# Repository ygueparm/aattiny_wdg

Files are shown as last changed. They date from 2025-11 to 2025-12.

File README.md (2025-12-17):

# Another ATtiny85 Watchdog for ESP32

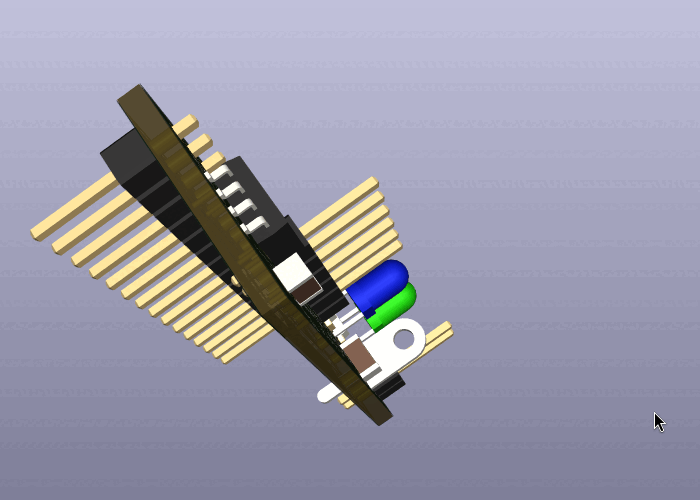
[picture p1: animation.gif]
Animation du projet


Ce projet fournit un **watchdog externe** pour ESP32, compatible avec **Arduino IDE 2.x**.

---

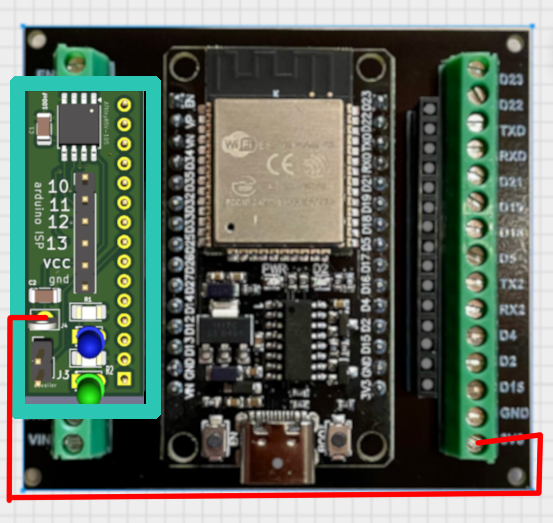
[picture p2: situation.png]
mise en situation


## 🔧 Code à inclure dans votre projet ESP32

```cpp
#define WATCHDOG_EXT         25 // IO ESP32

// Configuration du watchdog
extern bool watchdogState;
extern unsigned long previousMillisWD;
extern const long intervalWD;

void setup() {
  unsigned long previousMillisWD = 0; 
const long intervalWD = 200;  //clignotement 500 >1.6hz
bool watchdogState = true;
}

void loop() {
  // Watchdog externe créant un clignotement < 1.6 Hz
  unsigned long currentMillisWD = millis();

  if (currentMillisWD - previousMillisWD >= intervalWD) {
    previousMillisWD = currentMillisWD;
    watchdogState = !watchdogState;  // Inverse l'état
    digitalWrite(WATCHDOG_EXT, watchdogState);
  }

  // ... reste de votre code
}
```

---

# 🔌 Programmation ISP de l'ATtiny85

Pour programmer l'ATtiny85, vous devez utiliser **Arduino comme ISP**. NE SURTOUT PAS CONNECTEZ la carte a lesp32 pendant la programmation

brochage pour utiliser larduino uno comme programateur : 

'''
| Arduino Uno | ATtiny85 (broche physique) | Sérigraphie | Fonction |
| --- | --- | --- | --- |
| **10** | 1 | **P5** | RESET |
| **11** | 5 | **P0** | MOSI |
| **12** | 6 | **P1** | MISO |
| **13** | 7 | **P2** | SCK |
| **5V** | 8 | **VCC** | Alim +5V |
| **GND** | 4 | **GND** | Masse |
'''

## 1. Charger ArduinoISP

Dans l'IDE Arduino :

* *File > Examples > ArduinoISP*
* Téléversez sur votre Arduino UNO/Nano (le programmateur).

## 2. Ajouter la carte ATtiny85

* *File > Preferences*
* Dans **Additional board manager URLs**, ajoutez :

```
https://raw.githubusercontent.com/damellis/attiny/ide-1.6.x-boards-manager/package_damellis_attiny_index.json
```

Ensuite :

* *Tools > Board > Boards Manager*
* Recherchez **attiny** et installez.

## 3. Configuration

Dans *Tools* :

* **Board** : ATtiny85
* **Clock** : 1 MHz (interne)
* **Programmer** : Arduino as ISP

###  Première utilisation de l'ATtiny85

1. Ne soudez que l'ATtiny85 et les pins de programmation.
2. *Tools > Burn Bootloader* (installe les fuses corrects).
3. Votre ATtiny85 est maintenant prêt pour le projet.

 * fichier .ino >   aattiny_wdg/attiny_watchdog/attiny_watchdog.ino
 * vous pouvez soudez le reste des composants ! et le mettre en place
---

# 🏭 Production JLCPCB

Rendez-vous dans :

```
aattiny_wdg/attiny/production/
```

## ✔ Pour fabriquer uniquement le PCB

Utilisez **attiny.zip**, puis :

* envoyez-le sur JLCPCB ou PCBWay
* vous recevrez les PCB nus, à souder vous-même

## ✔ Pour la production complète (avec composants)

Les autres fichiers du dossier sont prévus pour l'assemblage automatisé.

---

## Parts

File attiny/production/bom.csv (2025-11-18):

Designator | Footprint | Quantity | Value | LCSC Part #
C1, C2 | 1206 | 2 | 100nf
D1, D2 | LED_D1.8mm_W3.3mm_H2.4mm | 2 | LED
J1 | PinHeader_1x06_P2.54mm_Vertical | 1 | arduino
J2 | PinHeader_1x15_P2.54mm_Vertical | 1 | esp32
J3 | PinHeader_1x02_P2.54mm_Vertical | 1 | cavalier
J4 | Pin_D1.1mm_L10.2mm_W3.5mm_Flat | 1 | Conn_01x01
R1, R2 | 1206 | 2 | R
U1 | SOIC-8_5.3x5.3mm_P1.27mm | 1 | ATtiny85V-10S

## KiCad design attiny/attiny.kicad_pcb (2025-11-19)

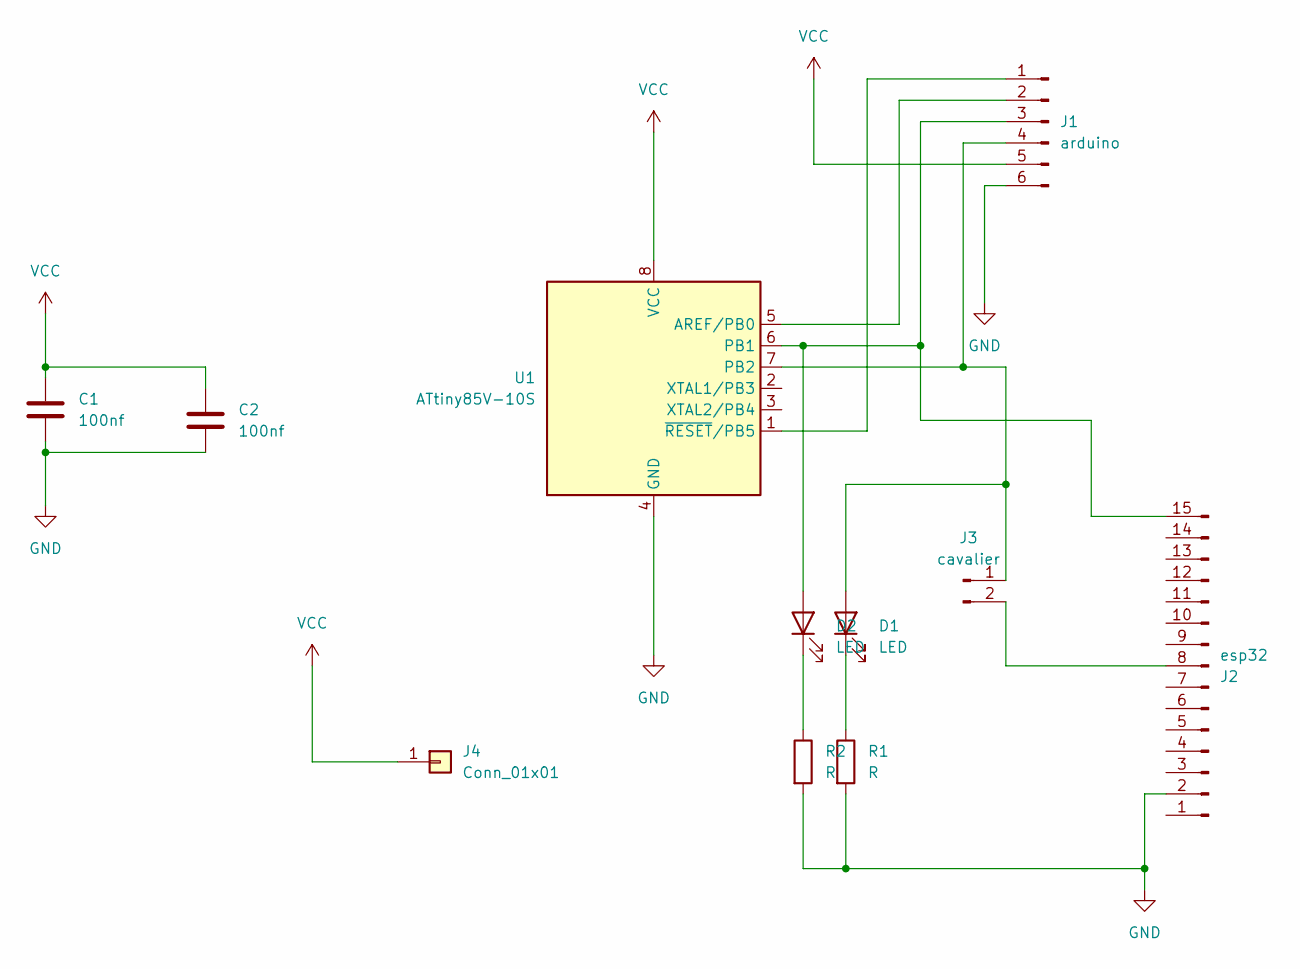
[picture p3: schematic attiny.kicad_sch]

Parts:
C1, C2: 100nf; C_1206_3216Metric
D1, D2: LED; LED_D1.8mm_W3.3mm_H2.4mm
J1: arduino; PinHeader_1x06_P2.54mm_Vertical
J2: esp32; PinHeader_1x15_P2.54mm_Vertical
J3: cavalier; PinHeader_1x02_P2.54mm_Vertical
J4: Conn_01x01; Pin_D1.1mm_L10.2mm_W3.5mm_Flat
R1, R2: R; LED_1206_3216Metric_Pad1.42x1.75mm_HandSolder
U1: ATtiny85V-10S; SOIC-8_5.3x5.3mm_P1.27mm

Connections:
GND: C1.2, C2.2, J1.6, J2.2, R1.2, R2.2, U1.4 (GND)
unnamed: D1.2 (A), J1.4, J3.1, U1.7 (PB2)
unnamed: D1.1 (K), R1.1
unnamed: D2.2 (A), J1.3, J2.15, U1.6 (PB1)
unnamed: D2.1 (K), R2.1
unnamed: J1.1, U1.1 (~RESET/PB5)
unnamed: J1.2, U1.5 (AREF/PB0)
unnamed: J2.8, J3.2
VCC: C1.1, C2.1, J1.5, J4.1, U1.8 (VCC)

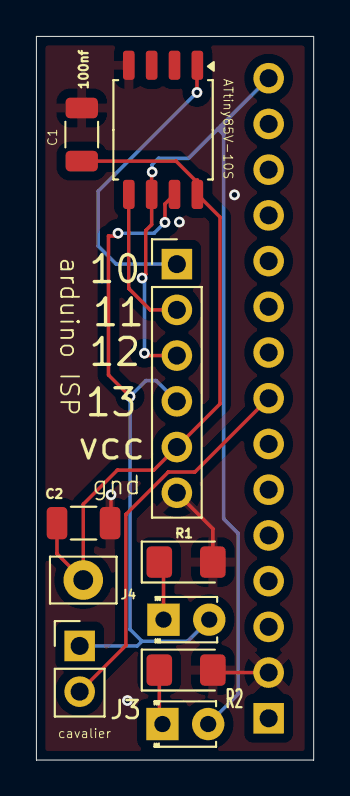
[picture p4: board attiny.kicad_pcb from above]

Board: 2 copper layers, 15.4 x 40.2 mm, 11 parts (1 on the bottom side), 9 nets.

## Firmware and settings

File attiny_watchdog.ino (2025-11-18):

#include <Arduino.h>
#include <avr/wdt.h>

const byte WATCHDOG_INPUT = 2;        // PB2 - Signal de l'ESP32
const byte RESET_PIN = 1;             // PB1 - Contrôle le RESET de l'ESP32
const unsigned long TIMEOUT = 4000;   // 4 secondes sans signal = reset
const unsigned long RESET_DURATION = 1000; // Durée du pulse de reset (500ms)

unsigned long lastKick = 0;
unsigned long resetStartTime = 0;
bool resetting = false;


static inline void wdt_init(uint8_t t) {
  uint8_t s = SREG; cli();
  MCUSR &= ~(1<<WDRF);
  WDTCR |= (1<<WDCE)|(1<<WDE);
  WDTCR = (1<<WDE) | t;
  SREG = s;
}

void setup() {
  pinMode(WATCHDOG_INPUT, INPUT_PULLUP);
  pinMode(RESET_PIN, OUTPUT);
  digitalWrite(RESET_PIN, HIGH);  // HIGH = fonctionnement normal
  
  lastKick = millis();  // Initialise le timer au démarrage
  wdt_init(8);          // 1 s, mode RESET pour le wdg interne
}

void loop() {
  wdt_reset();// reveil le wd interne du tiny


  unsigned long currentTime = millis();

  if (resetting && (currentTime - resetStartTime > 10000)) {
  digitalWrite(RESET_PIN, HIGH);
  resetting = false;
}

  // Détection du signal "kick" de l'ESP32
  if (digitalRead(WATCHDOG_INPUT) == LOW) {
    lastKick = currentTime;
    
    // Si on était en train de reset, on annule
    if (resetting) {
      resetting = false;
      digitalWrite(RESET_PIN, HIGH);
    }
  }
  
  // Gestion du reset
  if (resetting) {
    // Fin du pulse de reset
    if (currentTime - resetStartTime >= RESET_DURATION) {
      digitalWrite(RESET_PIN, HIGH);  // Relâche le reset
      resetting = false;
      lastKick = currentTime;  // Réinitialise le timer
    }
  } else {
    // Vérification du timeout
    if (currentTime - lastKick > TIMEOUT) {
      // Déclenche le reset de l'ESP32
      digitalWrite(RESET_PIN, LOW);  // Active le reset (LOW)
      resetStartTime = currentTime;
      resetting = true;
    }
  }
}

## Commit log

2025-11-18 Description de vos modifications
2025-11-18 Ajout projet complet ATTiny WDG avec PCB, schematics et Gerbers
    [attiny-B_Courtyard.gbr, attiny-B_Cu.gbr, attiny-B_Fab.gbr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]
2025-11-18 Ajout du code arduino-ide pour l'attiny85
2025-11-19 fichier production jlcpcb
    [attiny-B_Courtyard.gbr, attiny-B_Cu.gbr, attiny-B_Fab.gbr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]
2025-11-19 correction erreur serigraphie + nouveau fichier de production
    [attiny.kicad_pcb, positions.csv]
2025-11-19 correction routage mineur
    [attiny.kicad_pcb]
2025-11-19 mise a jour reference resistance avec ref jlcsc
    [attiny.kicad_sch]
2025-11-19 ajout configuration kicad ignore
